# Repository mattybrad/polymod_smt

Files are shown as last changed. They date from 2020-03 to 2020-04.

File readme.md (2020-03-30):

# PolyMod SMT test

This will be a small polyphonic digital modular synthesizer, using a Teensy 3.2. The design is based on my tutorial from Hackspace magazine (issue 17), and was also featured in the Book of Making (volume 2). Currently this is a work in progress, so don't go ordering any PCBs just yet. This is really just a project for me to get some practice designing with surface-mount components and specifying for a pick-and-place machine, which I haven't done before.

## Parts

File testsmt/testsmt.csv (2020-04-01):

Comment | Designator | Footprint | LCSC
0.1uF | C1 | Capacitor_SMD:C_0805_2012Metric
10uF | C2 | Capacitor_Tantalum_SMD:CP_EIA-3216-18_Kemet-A
LED | D1,D4,D3,D6,D5,D8,D7,D10,D9 | LED_SMD:LED_0805_2012Metric
1N4148 | D2 | Diode_SMD:D_SOD-123
MountingHole | H1,H2,H3,H4 | polymodsmt:MountingHole_3.2mm_M3
DIN-5_180degree | J1 | polymodsmt:MIDI_DIN5
Conn_01x16 | J2,J3,J4 | Connector_PinSocket_2.54mm:PinSocket_1x16_P2.54mm_Vertical
AudioJack3_Ground_Switch | J5 | polymodsmt:Tayda_3.5mm_stereo_TRS_jack_A-853
220 | R2 | Resistor_SMD:R_0805_2012Metric
470 | R3 | Resistor_SMD:R_0805_2012Metric
R_PHOTO | R4 | Connector_PinHeader_2.54mm:PinHeader_1x02_P2.54mm_Vertical
10K | R5,R7 | Resistor_SMD:R_0805_2012Metric
R_FORCE | R6 | Connector_PinHeader_2.54mm:PinHeader_1x02_P2.54mm_Vertical
68 | R9,R8,R11,R10,R13,R12,R15,R14,R1 | Resistor_SMD:R_0805_2012Metric
R_POT | RV1,RV2,RV3,RV4,RV5,RV6,RV7 | polymodsmt:Potentiometer_Alps_RK09K_Single_Vertical
6N138 | U1 | Package_DIP:SMDIP-8_W9.53mm
Teensy3.2 | U2 | teensy:Teensy30_31_32_LC
4051 | U4,U7,U3,U6,U5 | Package_SO:SOIC-16_3.9x9.9mm_P1.27mm
74HC595 | U8 | Package_SO:SOIC-16_3.9x9.9mm_P1.27mm

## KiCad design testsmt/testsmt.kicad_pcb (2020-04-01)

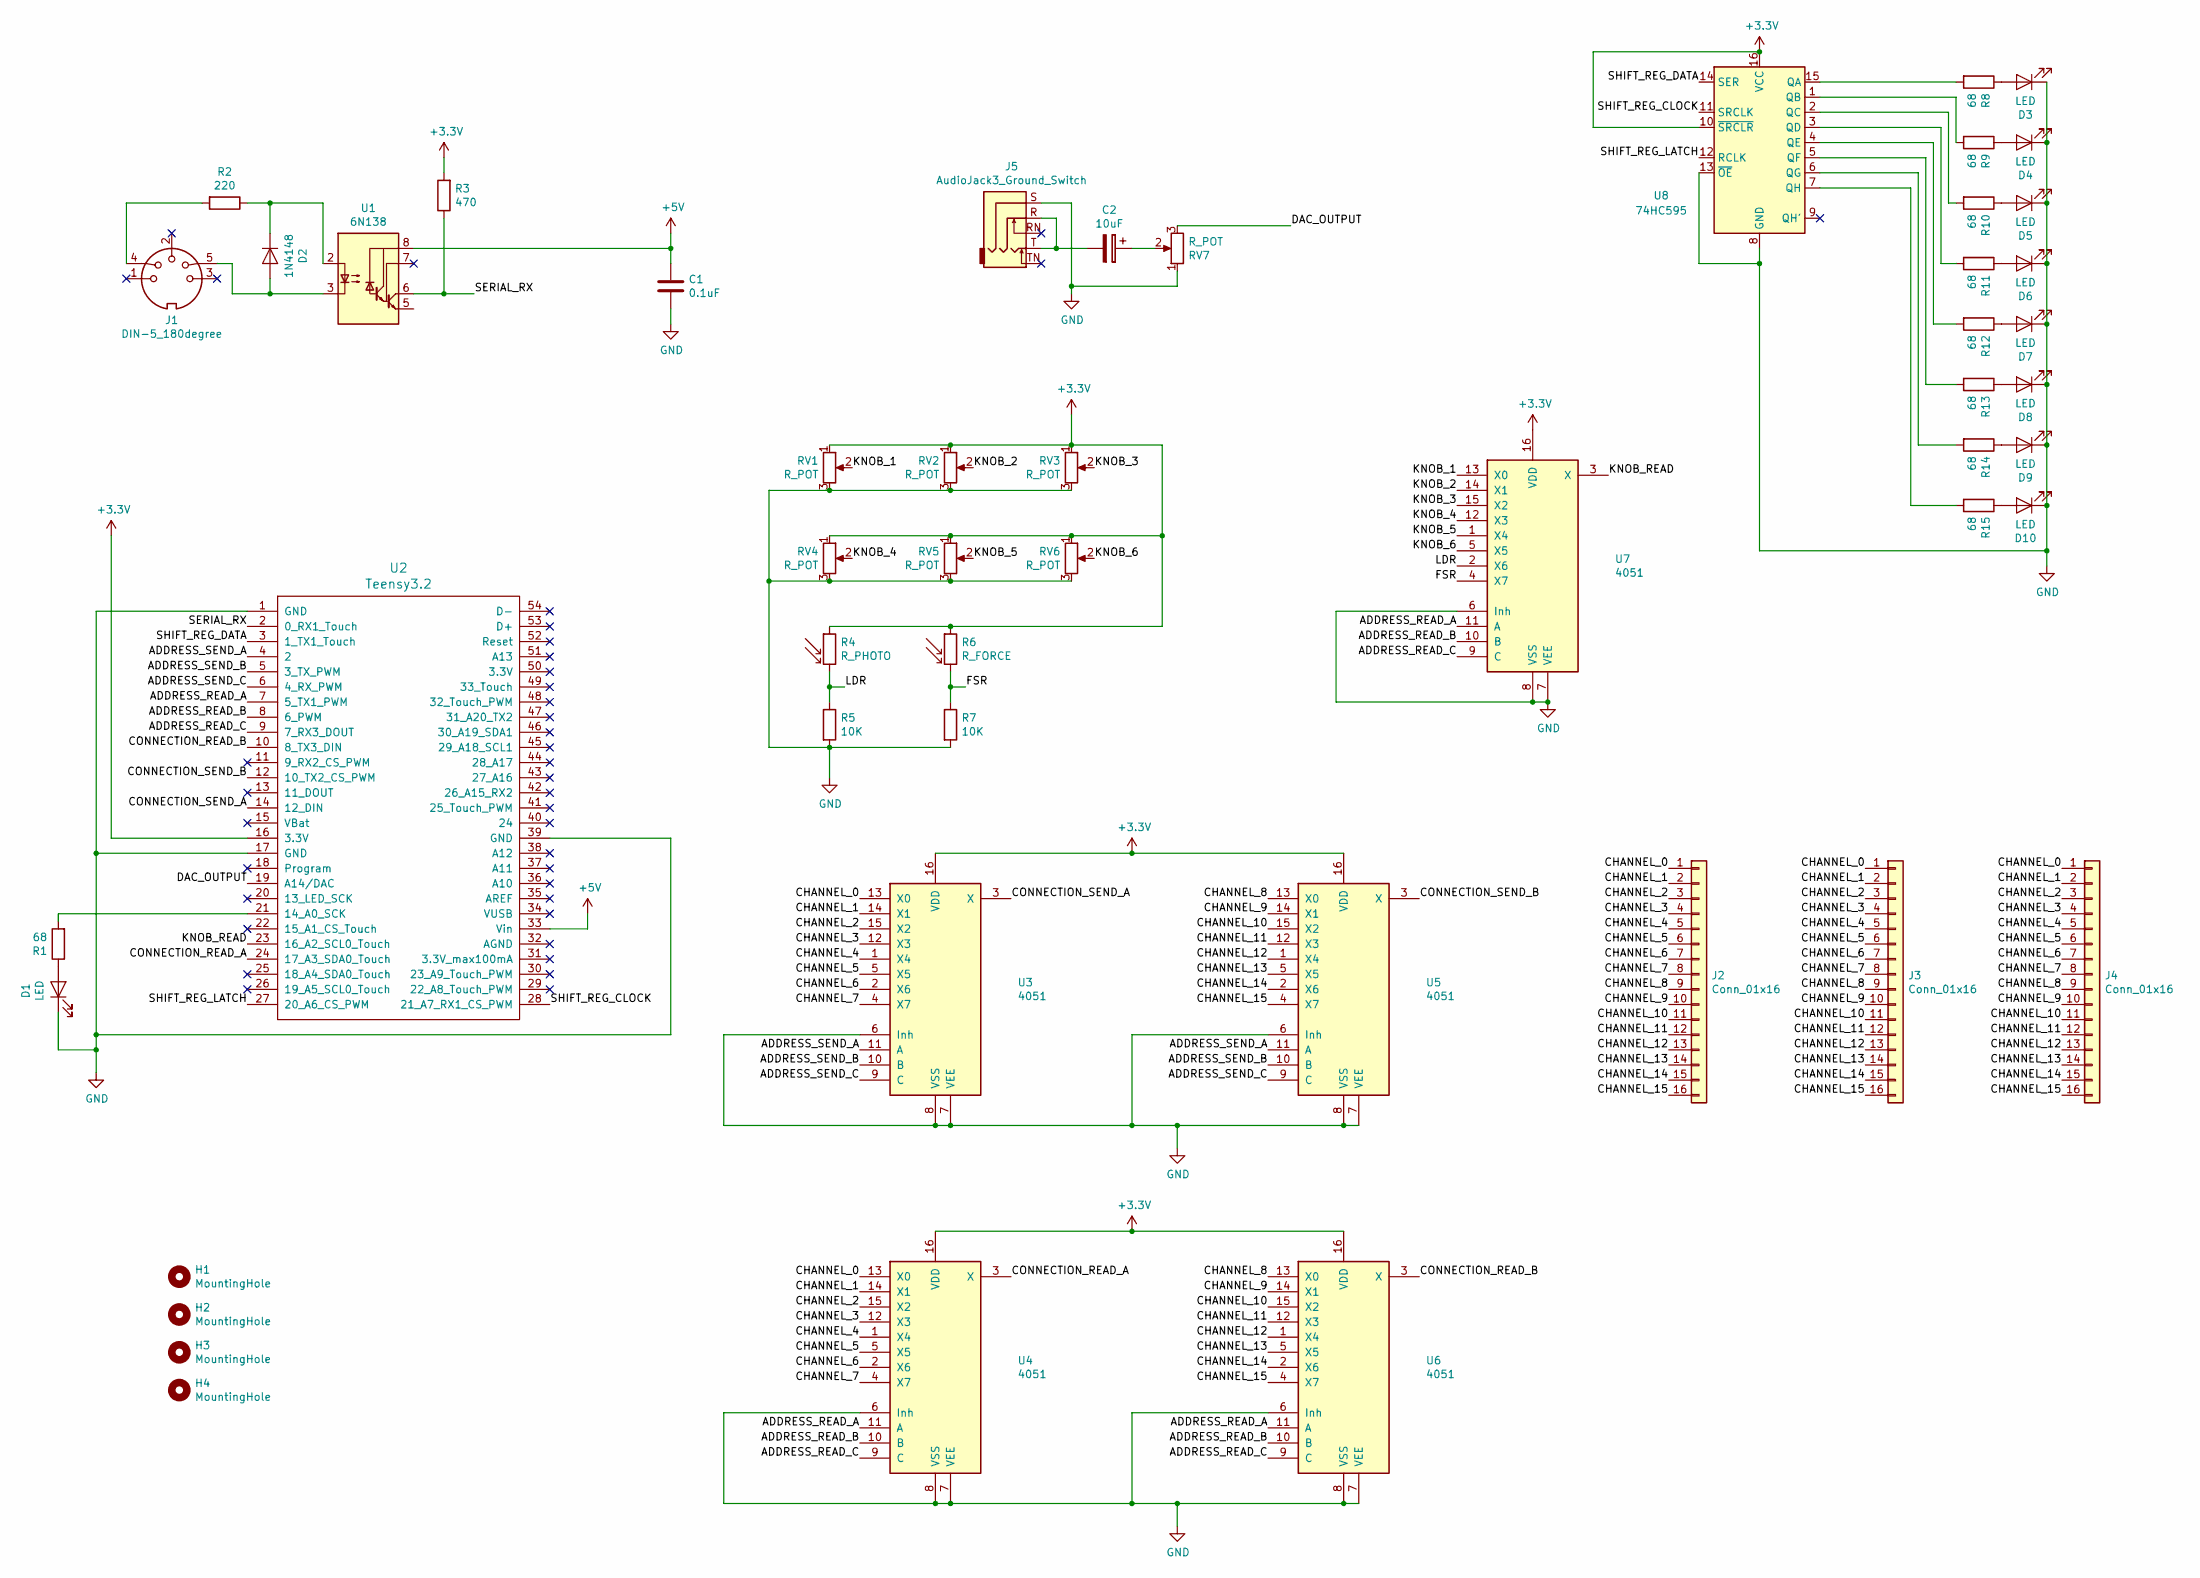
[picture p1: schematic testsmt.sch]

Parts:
C1: 0.1uF; C_0805_2012Metric
C2: 10uF; CP_EIA-3216-18_Kemet-A
D1, D3, D4, D5, D6, D7, D8, D9, D10: LED; LED_0805_2012Metric
D2: 1N4148; D_SOD-123
H1, H2, H3, H4: MountingHole; MountingHole_3.2mm_M3
J1: DIN-5_180degree; MIDI_DIN5
J2, J3, J4: Conn_01x16; PinSocket_1x16_P2.54mm_Vertical
J5: AudioJack3_Ground_Switch; Tayda_3.5mm_stereo_TRS_jack_A-853
R1, R8, R9, R10, R11, R12, R13, R14, R15: 68; R_0805_2012Metric
R2: 220; R_0805_2012Metric
R3: 470; R_0805_2012Metric
R4: R_PHOTO; PinHeader_1x02_P2.54mm_Vertical
R5, R7: 10K; R_0805_2012Metric
R6: R_FORCE; PinHeader_1x02_P2.54mm_Vertical
RV1, RV2, RV3, RV4, RV5, RV6, RV7: R_POT; Potentiometer_Alps_RK09K_Single_Vertical
U1: 6N138; SMDIP-8_W9.53mm
U2: Teensy3.2; Teensy30_31_32_LC
U3, U4, U5, U6, U7: 4051; SOIC-16_3.9x9.9mm_P1.27mm
U8: 74HC595; SOIC-16_3.9x9.9mm_P1.27mm

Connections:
+3V3: R3.2, R4.1, R6.1, RV1.1, RV2.1, RV3.1, RV4.1, RV5.1, RV6.1, U2.16 (3.3V), U3.16 (VDD), U4.16 (VDD), U5.16 (VDD), U6.16 (VDD), U7.16 (VDD), U8.10 (~SRCLR), U8.16 (VCC)
+5V: C1.1, U1.8 (VCC), U2.33 (Vin)
/ADDRESS_READ_A: U2.7 (5_TX1_PWM), U4.11 (A), U6.11 (A), U7.11 (A)
/ADDRESS_READ_B: U2.8 (6_PWM), U4.10 (B), U6.10 (B), U7.10 (B)
/ADDRESS_READ_C: U2.9 (7_RX3_DOUT), U4.9 (C), U6.9 (C), U7.9 (C)
/ADDRESS_SEND_A: U2.4 (2), U3.11 (A), U5.11 (A)
/ADDRESS_SEND_B: U2.5 (3_TX_PWM), U3.10 (B), U5.10 (B)
/ADDRESS_SEND_C: U2.6 (4_RX_PWM), U3.9 (C), U5.9 (C)
/CHANNEL_0: J2.1, J3.1, J4.1, U3.13 (X0), U4.13 (X0)
/CHANNEL_1: J2.2, J3.2, J4.2, U3.14 (X1), U4.14 (X1)
/CHANNEL_2: J2.3, J3.3, J4.3, U3.15 (X2), U4.15 (X2)
/CHANNEL_3: J2.4, J3.4, J4.4, U3.12 (X3), U4.12 (X3)
/CHANNEL_4: J2.5, J3.5, J4.5, U3.1 (X4), U4.1 (X4)
/CHANNEL_5: J2.6, J3.6, J4.6, U3.5 (X5), U4.5 (X5)
/CHANNEL_6: J2.7, J3.7, J4.7, U3.2 (X6), U4.2 (X6)
/CHANNEL_7: J2.8, J3.8, J4.8, U3.4 (X7), U4.4 (X7)
/CHANNEL_8: J2.9, J3.9, J4.9, U5.13 (X0), U6.13 (X0)
/CHANNEL_9: J2.10, J3.10, J4.10, U5.14 (X1), U6.14 (X1)
/CHANNEL_10: J2.11, J3.11, J4.11, U5.15 (X2), U6.15 (X2)
/CHANNEL_11: J2.12, J3.12, J4.12, U5.12 (X3), U6.12 (X3)
/CHANNEL_12: J2.13, J3.13, J4.13, U5.1 (X4), U6.1 (X4)
/CHANNEL_13: J2.14, J3.14, J4.14, U5.5 (X5), U6.5 (X5)
/CHANNEL_14: J2.15, J3.15, J4.15, U5.2 (X6), U6.2 (X6)
/CHANNEL_15: J2.16, J3.16, J4.16, U5.4 (X7), U6.4 (X7)
/CONNECTION_READ_A: U2.24 (17_A3_SDA0_Touch), U4.3 (X)
/CONNECTION_READ_B: U2.10 (8_TX3_DIN), U6.3 (X)
/CONNECTION_SEND_A: U2.14 (12_DIN), U3.3 (X)
/CONNECTION_SEND_B: U2.12 (10_TX2_CS_PWM), U5.3 (X)
/DAC_OUTPUT: RV7.3, U2.19 (A14/DAC)
/FSR: R6.2, R7.1, U7.4 (X7)
/KNOB_1: RV1.2, U7.13 (X0)
/KNOB_2: RV2.2, U7.14 (X1)
/KNOB_3: RV3.2, U7.15 (X2)
/KNOB_4: RV4.2, U7.12 (X3)
/KNOB_5: RV5.2, U7.1 (X4)
/KNOB_6: RV6.2, U7.5 (X5)
/KNOB_READ: U2.23 (16_A2_SCL0_Touch), U7.3 (X)
/LDR: R4.2, R5.1, U7.2 (X6)
/SERIAL_RX: R3.1, U1.6 (VO2), U2.2 (0_RX1_Touch)
/SHIFT_REG_CLOCK: U2.28 (21_A7_RX1_CS_PWM), U8.11 (SRCLK)
/SHIFT_REG_DATA: U2.3 (1_TX1_Touch), U8.14 (SER)
/SHIFT_REG_LATCH: U2.27 (20_A6_CS_PWM), U8.12 (RCLK)
GND: C1.2, D1.1 (K), D3.1 (K), D4.1 (K), D5.1 (K), D6.1 (K), D7.1 (K), D8.1 (K), D9.1 (K), D10.1 (K), J5.S, R5.2, R7.2, RV1.3, RV2.3, RV3.3, RV4.3, RV5.3, RV6.3, RV7.1, U2.1 (GND), U2.17 (GND), U2.39 (GND), U3.6 (Inh), U3.7 (VEE), U3.8 (VSS), U4.6 (Inh), U4.7 (VEE), U4.8 (VSS), U5.6 (Inh), U5.7 (VEE), U5.8 (VSS), U6.6 (Inh), U6.7 (VEE), U6.8 (VSS), U7.6 (Inh), U7.7 (VEE), U7.8 (VSS), U8.8 (GND), U8.13 (~OE)
unnamed: C2.1, RV7.2
unnamed: C2.2, J5.R, J5.T
unnamed: D1.2 (A), R1.1
unnamed: D2.1 (K), R2.1, U1.2 (C1)
unnamed: D2.2 (A), J1.5, U1.3 (C2)
unnamed: D3.2 (A), R8.1
unnamed: D4.2 (A), R9.1
unnamed: D5.2 (A), R10.1
unnamed: D6.2 (A), R11.1
unnamed: D7.2 (A), R12.1
unnamed: D8.2 (A), R13.1
unnamed: D9.2 (A), R14.1
unnamed: D10.2 (A), R15.1
unnamed: J1.4, R2.2
unnamed: R1.2, U2.21 (14_A0_SCK)
unnamed: R8.2, U8.15 (QA)
unnamed: R9.2, U8.1 (QB)
unnamed: R10.2, U8.2 (QC)
unnamed: R11.2, U8.3 (QD)
unnamed: R12.2, U8.4 (QE)
unnamed: R13.2, U8.5 (QF)
unnamed: R14.2, U8.6 (QG)
unnamed: R15.2, U8.7 (QH)

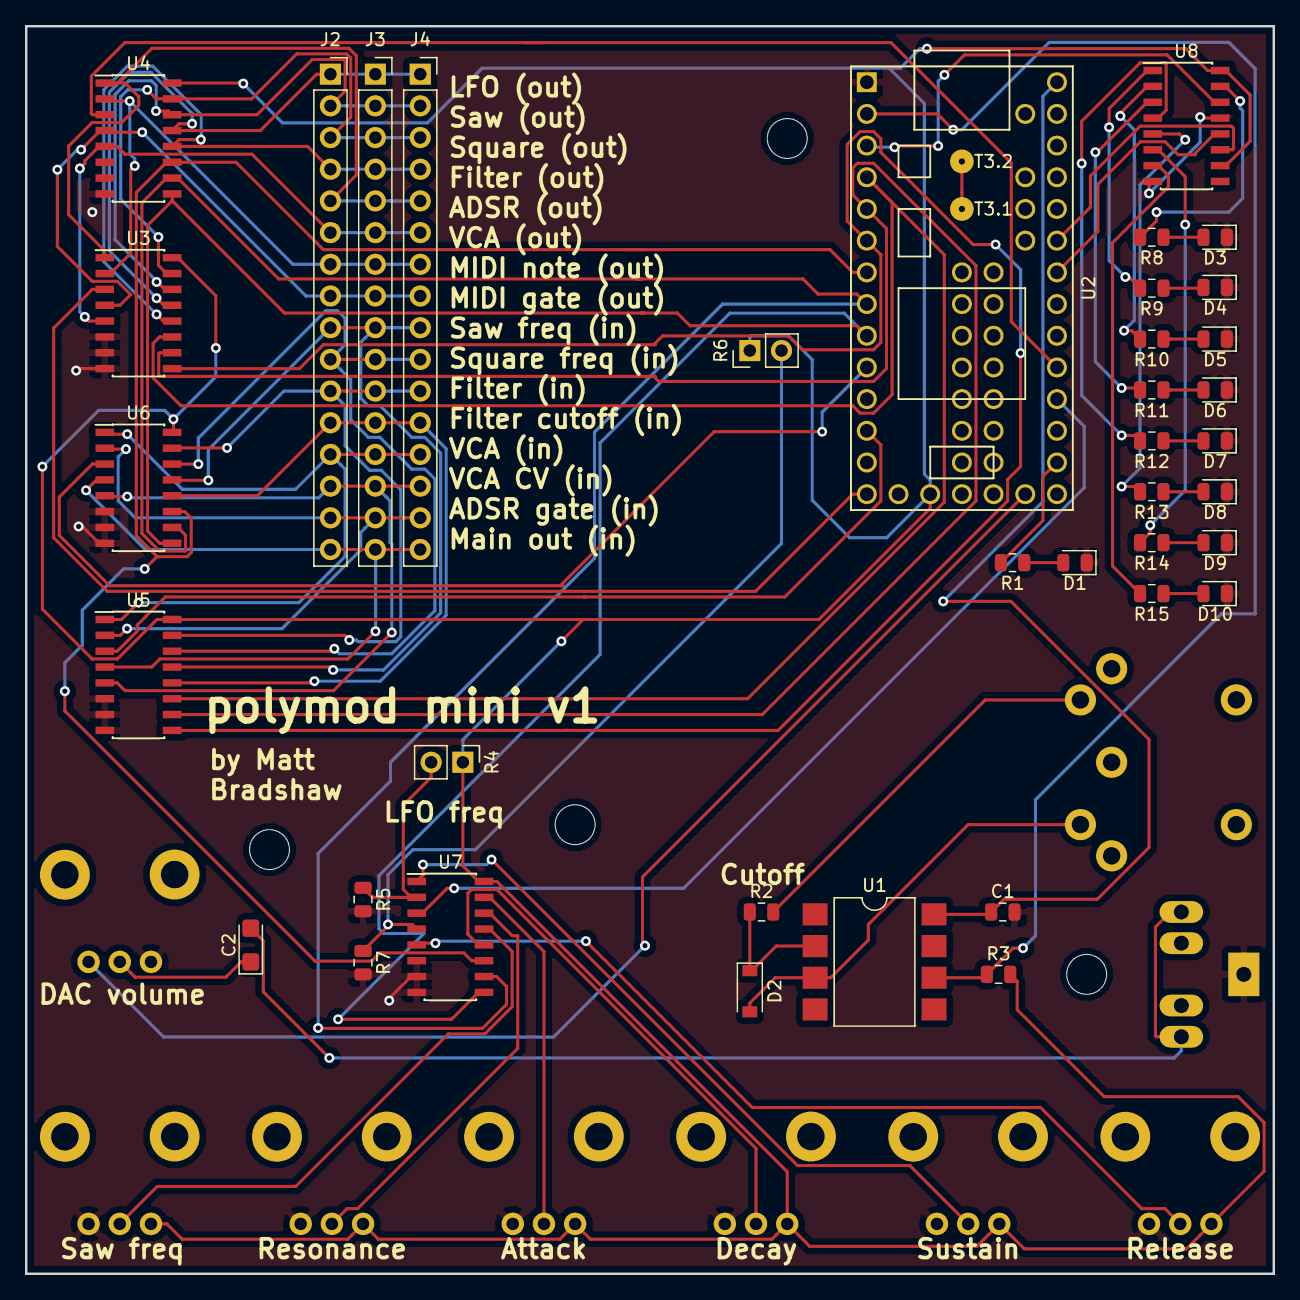
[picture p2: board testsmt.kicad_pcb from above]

Board: 2 copper layers, 100.0 x 100.0 mm, 51 parts (0 on the bottom side), 66 nets.

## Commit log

2020-03-30 schematic nearly done
    [testsmt.sch]
2020-03-30 schematic looking good
    [testsmt.sch]
2020-03-30 nearly done adding footprints
    [testsmt.sch]
2020-03-30 footprints hopefully done
    [testsmt.sch]
2020-03-30 started laying out board
    [testsmt.sch]
2020-03-30 about to try out some routing
    [testsmt.kicad_pcb]
2020-03-30 started routing
    [testsmt.kicad_pcb]
2020-03-30 routing going well
    [testsmt.kicad_pcb]
2020-03-31 more routing...
    [testsmt.kicad_pcb]
2020-03-31 think the hard routing is done...?
    [testsmt.kicad_pcb]
2020-03-31 computer keeps crashing
    [testsmt.kicad_pcb]
2020-04-01 moving things
    [testsmt.kicad_pcb]
2020-04-01 fsr in place
    [testsmt.kicad_pcb]
2020-04-01 pretty happy with layout
    [testsmt.kicad_pcb]
2020-04-01 routing routing routing
    [testsmt.kicad_pcb]
2020-04-01 13 unrouted left
    [testsmt.kicad_pcb]
2020-04-01 where is the last unrouted connection?!
    [testsmt.kicad_pcb]
2020-04-01 routing done
    [testsmt.kicad_pcb]
2020-04-01 nearly there
    [testsmt.kicad_pcb]
2020-04-01 mounting holes
    [testsmt.kicad_pcb, testsmt.sch]
2020-04-01 gerbers etc, and manually fixed rotations
    [testsmt-B.Cu.gbr, testsmt-B.Mask.gbr, testsmt-B.Paste.gbr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]
2020-04-01 fixed rotations again, apparently they go anticlockwise
    [testsmt-top-pos.csv]
2020-04-01 pcbs ordered!
    [testsmt.kicad_pcb]
